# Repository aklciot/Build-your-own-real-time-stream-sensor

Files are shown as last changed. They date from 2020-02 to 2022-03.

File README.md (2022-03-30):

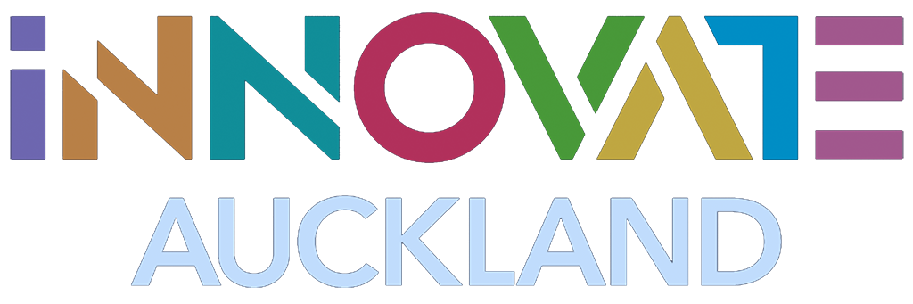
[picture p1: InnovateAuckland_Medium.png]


# Stream Water EC, Temperature and Level Sensor
Build your own automated water quality EC sensor and transmit the data over LoRa radio.
<br>View a live example here: 
https://live.innovateauckland.nz/dashboard/28a59570-c8a9-11ea-a129-5da81effbbe6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

## Selection Criteria for Stream EC Sensor Location:

1.	Fresh water only, non-tidal. The EC 0.1 K sensor is not suited to saltwater.
2.	An active community group willing to periodically check on the sensor, take samples and photographs when events happen and as required
3.	If the sensor will also measure water height, an over water mounting location not exceeding 2.5M above normal water level, this is because the max sonar range is 3.5 Meters
4.	An EC sensor tether location that allows the sensor to move freely in or near the main flow. The sensor cable is around 4 metres in length. This way, water flow automatically maintains a consistent sensor location.
5.	A network gateway location with line of sight 1-2Km of the sensing location.
6.	Ability to easily access the senor unit for maintenance, cleaning and battery changes.
7.	Protecting the sensor in public locations. It is preferrable to locate the sensor for good measurement over avoiding theft or vandalism.  Consider how to disguise or cover the senor in areas that are accessible by the public.

## User Guide
Please read the user guide included here to learn about the sensor installation and operation.
https://github.com/aklciot/StreamECSensor/blob/master/Userguide/USER_GUIDE_WaterEC_Sensor_0.8.8.pdf

## Compiling and loading
This code can be compiled on a standard Arduino GUI.
### Libraries
The following libraries are required:
- OneWire.h (connects data for the dallas sensor)
- DallasTemperature.h (DS18B20 digital thermometer)
- Adafruit_SleepyDog.h  (Power management)
- RH_RF95.h (Radiohead driver for the Hope LoRa radio)
- Ultrasonic.h (driver for the grove ultrasonic sensor)

### PLEASE NOTE:
This sensor is designed to work with the open source LoRa telemetry network and gateway described here:</br>
https://github.com/aklciot/TTGO-Gateway-repeater
</br>

## About this Sensor

### Who should use this guide:

This guide is for anyone interested in creating their own real-time environmental data sensing network.  It explains how to install and use the open source water quality sensor and the data network that makes your sensor data available on the internet.

Some of the concepts in the guide are quite technical, if you’re not sure or need clarification please email us at the address below.

We recommend you have access to people familiar with connecting computer peripherals and WiFi settings.

### What is real-time monitoring?
Low cost Real-time monitoring is an amazing new capability made possible by a collection of technologies commonly referred to as the internet of things (IOT). Most monitoring techniques involve a regular visit to the monitoring location where recordings are made and recorded manually. These visits can be weeks or months apart.  In real time monitoring, measurements are made automatically every few minutes and the information is immediately processed and stored on the internet. This  creates an up to date, long term and detailed record.

### Why is real time monitoring important?

Streams are very sensitive to weather and pollution events. These events can occur over a very short time, often after a few hours or minutes the event is over. Monthly sampling will miss most important events that occur in your stream.
With real time monitoring:

<b>Don’t miss events.</b> Things can change fast in a stream, if you’re not there to see it you’ll miss it, the sensor watches 24/7 and creates a continuous record.</br>
<b>Narrow down the cause.</b> If your stream is monitored at multiple points you can narrow down where and when an event occurred and its possible cause.</br>
<b>Create positive behaviours.</b> We all change how we behave if we know we’re being watched.  With the stream monitor people become aware that dumping and faults are more likely to be detected.</br>
<b>See the effect of restoration work.</b>  The sensor creates long term trend data. The improvements made by restoration work can be shown over time.</br>
<b>You can learn more about your stream and others.</b> Combing your data with the work done by others can lead to new insights previously unavailable.</br>

### How does the stream sensor work?
The sensor is intended to detect acute discharge events into urban waterways that would otherwise go unnoticed. 
It works by monitoring the water electrical conductivity (EC), temperature, and water level. 
Every few minutes the sensor sends data over <a href="https://en.wikipedia.org/wiki/LoRa" target="_blank">LoRa radio</a> to the internet where the time is recorded and the data is processed and stored. 
This sensor is based on low cost open source technology and as such is not a scientific grade water quality meter, however it is good enough to give meaningful information and warnings and let you know when it is time to take a closer look. 
To keep the cost (and maintenance) down, it does not currently monitor other stream health metrics such as dissolved oxygen (DO), pH, Phosphates, bacteria and nutrients.  Some of these will be added in the future though.

### What is EC (Electrical Conductivity in water)?
EC or Electrical Conductivity of water is its ability to conduct an electric current. Salts or other chemicals that dissolve in water can break down into positively and negatively charged ions. These free ions in the water conduct electricity, so the water electrical conductivity depends on the concentration of ions. 
Salinity and total dissolved solids (TDS) are used to calculate the EC of water, which helps to indicate the water’s purity. 
The purer the water the lower the conductivity. To give a real-life example, distilled water is almost an insulator, but saltwater is a very efficient electrical conductor.
<br>
<br>
The system includes the ability to alert on threshold events by SMS text, email or twitter. Data can also be extracted or forwarded to other systems for modeling and trending analysis.
<br>

## Change Log
- Version 2.4 Published to GitHub
- Version 2.3 Added MOSFET power control and grove ultrasonic sensor
- Version 2.2 Added EC K type Calibration to loop
- Version 2.1 Added f_ec = atof(EC); to convert char to float to resolve radio send fault
- Version 2.0 Installed Atlas Scientific EC K=0.1 sensor and EZO circuit.
- Version 1.3 Installed grove ultrasonic to improve power usage.
- Version 1.2 Changed to default LoRa radio spreading factor
- Version 1.1 Corrected water temperature and EC calculation
- Version 1.0 Initial Build

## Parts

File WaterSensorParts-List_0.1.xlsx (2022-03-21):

Parts List BOM: Urban Stream Sensor: Water level, Conductivity and Temperature
 | QTY | Part | Description | Supplier Website | Cost $NZ
 | 1 | Ultrasonic Distance Sensor - 3V or 5V - HC-SR04 compatible - RCWL-1601 | ultrasonic sensor to measure the water height | https://www.tinytronics.nl/shop/en/sensors/distance/ultrasonic-sensor-rcwl-1601
 |  |  |  | https://www.adafruit.com/product/4007 | 10
 | 5 | 4-core Round Screened Audio Cable - Sold per metre. CAT.NO: WB1510 | 5M Sensor Cable | https://www.jaycar.co.nz/4-core-round-screened-audio-cable-sold-per-metre/p/WB1510 | 10
 | 1 | Waterproof DS18B20 Digital temperature sensor + extras | Water temperatue sensor | https://www.adafruit.com/product/381 | 20
 | 1 | Feather 32u4 RFM95 LoRa Radio- 868 or 915 MHz - PRODUCT ID: 3078 | MCU controller CPU that runs the code for taking measurements and sending the data | https://www.adafruit.com/product/3078 | 70
 |  |  |  | https://nz.mouser.com/ProductDetail/Adafruit/3078?qs=AGnqjqvSJvKRStF%2FKXnSuQ%3D%3D
 | 1 | Power control MOSFET | N-Channel Enhancement Mode Field Effect Transistor | https://nz.mouser.com/ProductDetail/onsemi-Fairchild/2N7000?qs=FOlmdCx%252BAA2o%2FKZOTk%2F3hg%3D%3D | 2
 | 1 | Lithium Battery | AA Batteries, pack of four. | https://www.newworld.co.nz/shop/product/5028789_ea_000nw?name=ultimate-lithium-aa-battery | 25
 | 1 | DS18B20 Digital temperature sensor + extras PRODUCT ID: 374 | Air Temperature Sensor | https://www.adafruit.com/product/374 | 10
 | 1 | Atlas Scientific Water EC Conductivity | Conductivity Sensor K0.1 | https://www.atlas-scientific.com/product_pages/kits/ec_k0_1_kit.html | 500
 | 1 | LoRa Data Telemetry Gateway | 2Pcs Wemos® TTGO 868/915MHz SX1276 ESP32 LoRa 0.96 Inch Blue OLED Display bluetooth WIFI Module IOT Development Board | https://www.banggood.com/2Pcs-Wemos-TTGO-868915MHz-SX1276-ESP32-LoRa-0_96-Inch-Blue-OLED-Display-Bluetooth-WIFI-Module-p-1303190.html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 | 100
 | 1 | Sealed Polycarbonate Enclosure 115 x 90 x 55 | Box for housing the sensor | https://www.jaycar.co.nz/sealed-polycarbonate-enclosure-115-x-90-x-55/p/HB6217 | 25
 |  | Total: |  |  | 772

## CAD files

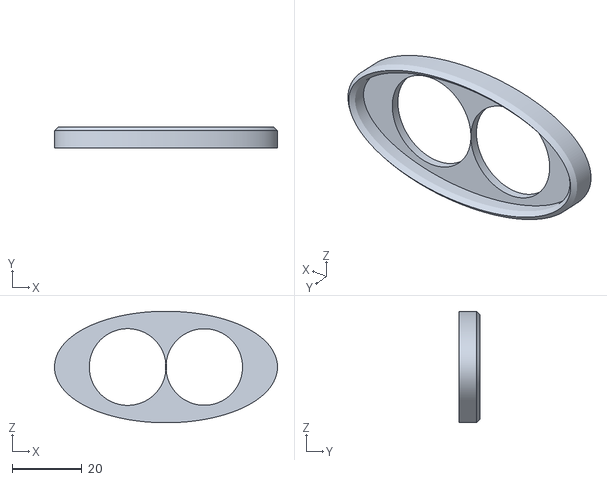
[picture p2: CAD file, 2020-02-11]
3D Files/OuterRing_V1.stl
64.0 x 6.00 x 32.0

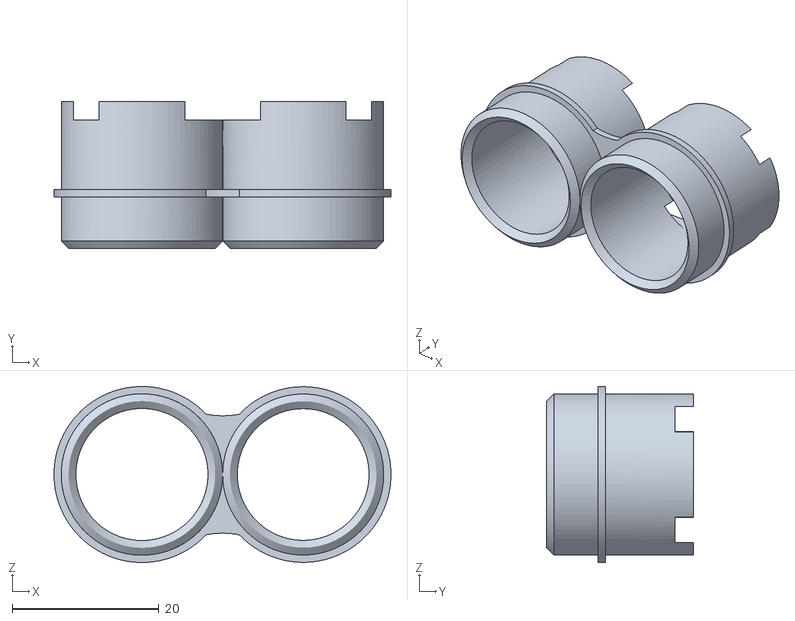
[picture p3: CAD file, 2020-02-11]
3D Files/Rings_V3.stl
45.9 x 20.0 x 24.0

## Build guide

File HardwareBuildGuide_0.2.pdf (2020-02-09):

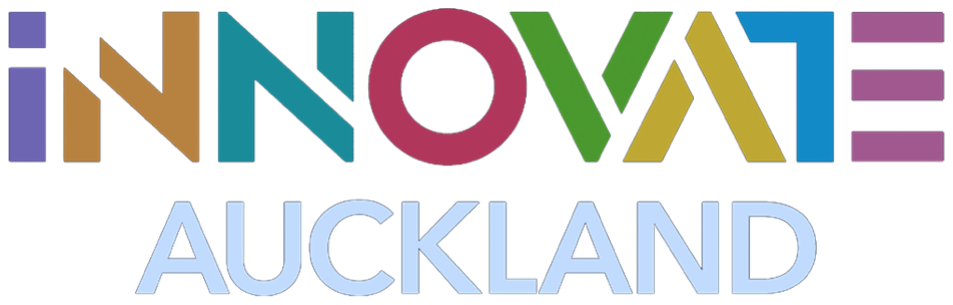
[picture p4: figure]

## Hardware Build Guide:

Water Quality Conductivity Temperature and Level Sensor

Build Guide version 0.2. Warren Davies Draft for Comment

Ultrasonic Sensor Mount with 3D printed insert.

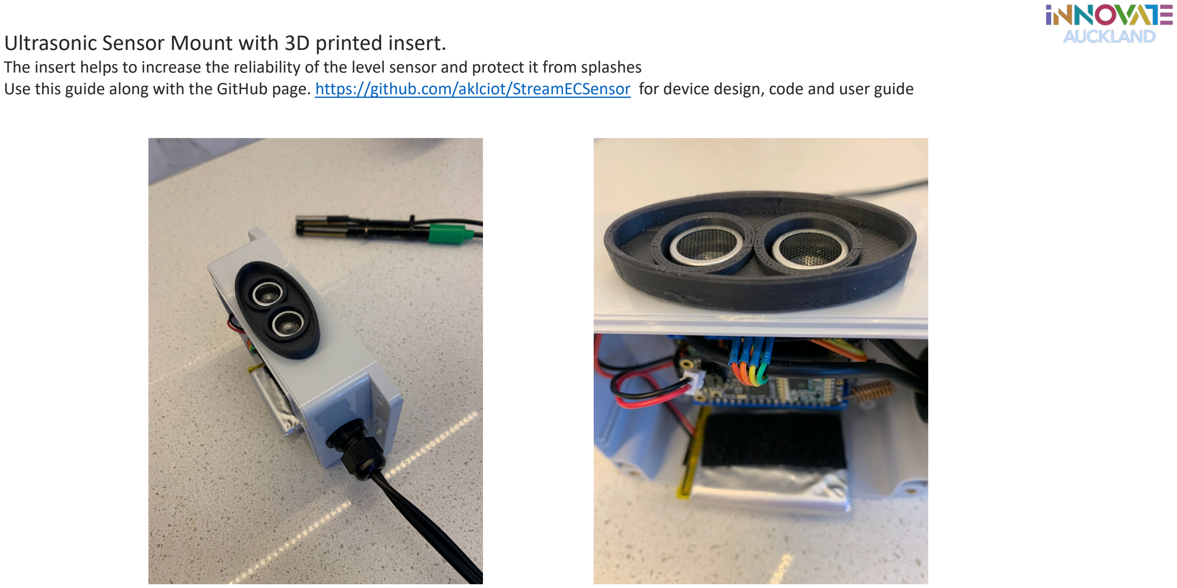
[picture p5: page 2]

The insert helps to increase the reliability of the level sensor and protect it from splashes
Use this guide along with the GitHub page. https://github.com/aklciot/StreamECSensor for device design, code and user guide

Internal Construction.

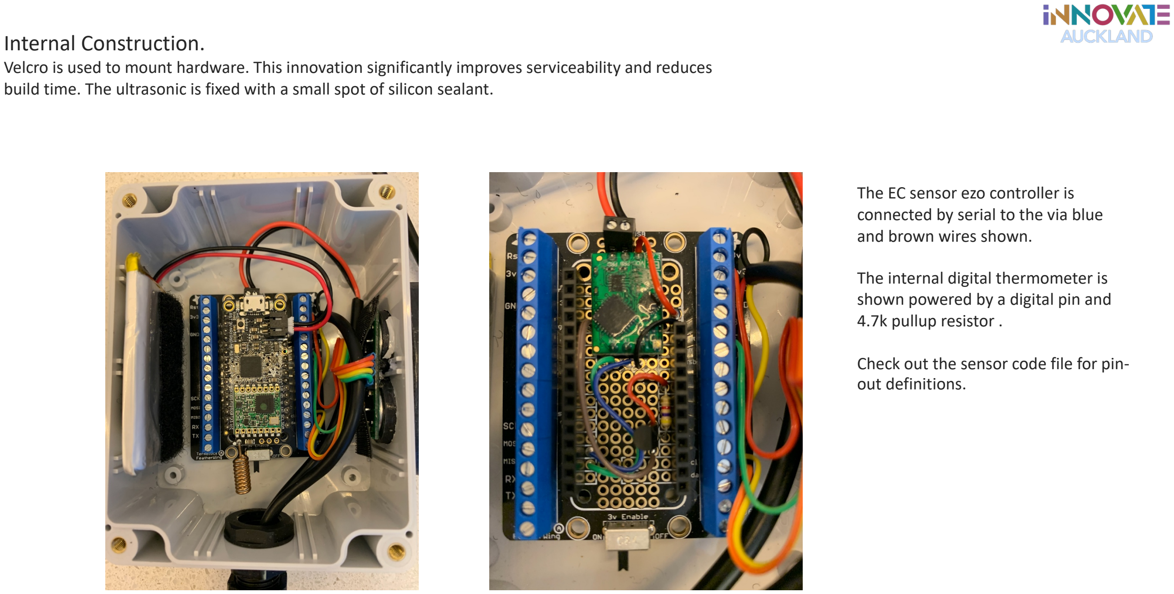
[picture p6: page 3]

Velcro is used to mount hardware. This innovation significantly improves serviceability and reduces build time. The ultrasonic is fixed with a small spot of silicon sealant.

The EC sensor ezo controller is connected by serial to the via blue and brown wires shown.

The internal digital thermometer is shown powered by a digital pin and 4.7k pullup resistor .

Check out the sensor code file for pinout definitions.

Sensor Tether Cable Construction.

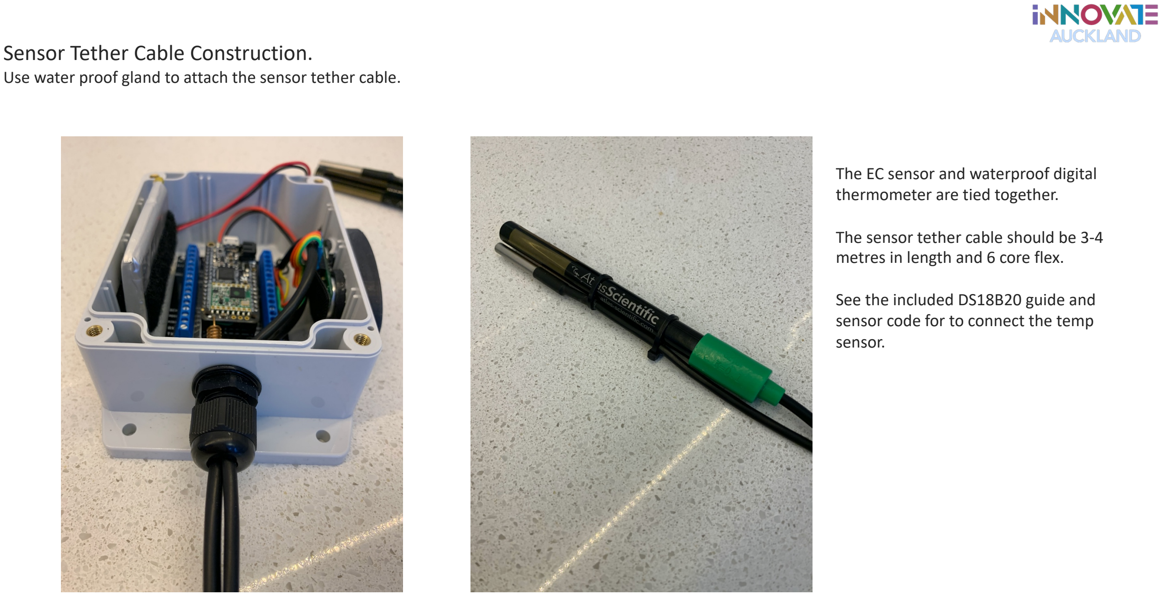
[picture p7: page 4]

Use water proof gland to attach the sensor tether cable.

The EC sensor and waterproof digital thermometer are tied together.

The sensor tether cable should be 3-4 metres in length and 6 core flex.

See the included DS18B20 guide and sensor code for to connect the temp sensor.

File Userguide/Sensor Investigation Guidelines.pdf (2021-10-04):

0

2

0

1

0

3

If you're in the area, observe any changes

in water clarity, level or smell.

Take note of any discolouration from paint,

detergent, oil, foam, sediment or presence

of wastewater, and understand the

potential origins of each.

# TAKE A CLOSER LOOK

Watercare - 09 442 2222 if sewage /

waste water.

Pollution Hotline - 09 377 3107 if

water is discoloured from paint,

detergent, oil, foam, sediment.

# REPORT

0

4

0

5

# Community Stream Sensor

## Investigation guideline

What does the stream normally look like, in

dry weather and after rain? What is the

typical pH level of the stream?

UNDERSTAND THE BASELINE | Review the EC in conjunction with the
| water level and temperature. An increase
| in EC and water level could indicate an
| event caused by heavy rain. An increase
| in EC, water level and temperature could
| indicate a first flush pollution event.

# ANALYSE THE TRENDS

If the stream looks & smells normal, you

can use your Wai Care care to test for pH

and Ammonia. Ammonia is an indicator

of wastewater, and pH an indicator of the

presence of pollutants. If the results are

outside of their thresholds (pH below 5

or over 9, Ammonia above 3) call

Pollution Hotline.

# SAMPLE

*If taking a sample, please remember to only to do so if wearing gloves and can safely access the stream bank. Follow your Wai Care Health & Safety plan

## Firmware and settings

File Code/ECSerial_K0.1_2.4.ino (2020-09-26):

// **********************************************************************************
// INNOVATE AUCKLAND Water Quality EC Sensor Version 2.4
// EZO-ECTM Embedded Conductivity Circuit Conductivity = μS/cm
// Adafruit featherM0 with LoRa RFM95, Dallas 18B20 sensors and sleepydog power management
// Includes 2X Dallas 18B20 digital Air and Water temperature sensors
// WD Version 2.4 Published to GitHub
// WD Version 2.3 Added MOSFET power control and grove ultrasonic sensor and library
// WD Version 2.2 Added EC K type Calibration to loop
// WD Version 2.1 Added f_ec = atof(EC); to convert char to float to resolve radio send fault
// WD Version 2.0 Installed Atlas Scientific EC K=0.1 sensor and EZO circuit.
// WD Version 1.3 Installed grove ultrasonic to improve power usage.
// WD Version 1.2 Changed to default LoRa radio spreading factor
// WD Version 1.1 Corrected water temperature and EC calculation
// WD Version 1.0 Initial Build
// **********************************************************************************

/*
The Non-Profit Open Software License version 3.0 (NPOSL-3.0)

Copyright (c) 2019 Innovate Auckland

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
This software may not be used for commercial purposes.

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

THE SOFTWARE IS PROVIDED "AS IS", WITHOUT WARRANTY OF ANY KIND, EXPRESS OR
IMPLIED, INCLUDING BUT NOT LIMITED TO THE WARRANTIES OF MERCHANTABILITY,
FITNESS FOR A PARTICULAR PURPOSE AND NONINFRINGEMENT. IN NO EVENT SHALL THE
AUTHORS OR COPYRIGHT HOLDERS BE LIABLE FOR ANY CLAIM, DAMAGES OR OTHER
LIABILITY, WHETHER IN AN ACTION OF CONTRACT, TORT OR OTHERWISE, ARISING FROM,
OUT OF OR IN CONNECTION WITH THE SOFTWARE OR THE USE OR OTHER DEALINGS IN THE
SOFTWARE
.*/

#include <OneWire.h>
#include <DallasTemperature.h>
#include <Adafruit_SleepyDog.h>
#include <RH_RF95.h>
#include "Ultrasonic.h"

char* Nodestr = "STRXX";   // Node ID
#define PWRLOOP 19         // Power down, n X 16sec power down


//************************************ Define Connections ***************************
// Settings for feather32u4 LoRa RFM95
/*
  #define RFM95_CS  8
  #define RFM95_RST 4
  #define RFM95_INT 7
  #define VBATPIN   A9 // voltage divider for battery measurement
  #define led       13
*/

// Settings for featherM0 LoRa RFM95
#define RFM95_RST    4
#define RFM95_CS     8
#define RFM95_INT    3
#define VBATPIN      A7 // voltage divider for battery measurement
#define RF95_FREQ 915.0
#define LED          13

#define SensorPWR    12
#define ONE_WIRE_BUS 6 // Dallas data wire is connected to pin 6


String inputstring = "";                              //a string to hold incoming data from the PC
String sensorstring = "";                             //a string to hold the data from the Atlas Scientific product
boolean input_string_complete = false;                //have we received all the data from the PC
boolean sensor_string_complete = false;               //have we received all the data from the Atlas Scientific product

char sensorstring_array[30];                        //we make a char array
char *EC;                                           //char pointer used in string parsing
char *TDS;                                          //char pointer used in string parsing
char *SAL;                                          //char pointer used in string parsing
char *GRAV;                                         //char pointer used in string parsing

// wd variables told hold string values
char Tstr[10];     // Air Temp
char Wstr[10];     // Water temp
char Dstr[10];     // Distance
char ECstr[10];    // EC Level
char Bstr[10];     // Battery Voltage

char buffer[50];
byte sendLen;

float Temp1, WTemp, Bat, f_ec, Dist;
int distance;


//************************************ Load Drivers ********************************

RH_RF95 rf95(RFM95_CS, RFM95_INT);        // wd load driver instance of the radio and name it "rf95"

OneWire oneWire(ONE_WIRE_BUS);            // Setup a oneWire instance to communicate with any OneWire devices

DallasTemperature sensors(&oneWire);      // Pass our oneWire reference to Dallas Temperature.

//Ultrasonic ultrasonic(10, 11);
Ultrasonic ultrasonic(10);  //grove 3 wire


void setup() {

  //while (!Serial);
  Serial.begin(9600);                                 //set baud rate for the hardware serial port_0 to 9600
  delay(100);
  Serial1.begin(9600);                               //set baud rate for the software serial port_1 to 9600

  Serial.println("Serial Started");

  pinMode(LED, OUTPUT);        // initialize digital pin as an output.
  pinMode(SensorPWR, OUTPUT);
  pinMode(RFM95_RST, OUTPUT);
  digitalWrite(RFM95_RST, HIGH);

  // manual reset
  digitalWrite(RFM95_RST, LOW);
  delay(10);
  digitalWrite(RFM95_RST, HIGH);
  delay(10);

  //wd initialise radio
  while (!rf95.init()) {
    Serial.println("LoRa radio init failed");
    while (1);
  }
 
  Serial.println("LoRa radio init OK!");

  // Defaults after init are 434.0MHz, modulation GFSK_Rb250Fd250, +13dbM
  if (!rf95.setFrequency(RF95_FREQ)) {
    Serial.println("setFrequency failed");
    while (1);
  }
  Serial.print("Set Freq to: "); Serial.println(RF95_FREQ);

  // wd set radio tx power and use PA false
  rf95.setTxPower(13, false);
  rf95.printRegisters();  //Print all the RFM95 register values
  /*
      // Start up the Dallas Temperature library
      sensors.begin();
  */

  inputstring.reserve(10);                            // set aside some bytes for receiving data from the PC
  sensorstring.reserve(30);                           // set aside some bytes for receiving data from Atlas Scientific product
  Serial1.print("Factory");                           // Factory rest EZO-EC Atlas Scientific
  Serial1.print('\r');
  delay(1000);
  Serial1.print("K,0.1");                             // Set K level of the EZO-EC Atlas Scientific product
  Serial1.print('\r');

  digitalWrite(LED, LOW);
  delay(50);
  digitalWrite(LED, HIGH);
  delay(50);
  digitalWrite(LED, LOW);
  delay(50);
  digitalWrite(LED, HIGH);
  delay(50);
  digitalWrite(LED, LOW);
  delay(5000);  //wait for recode

}


/**********wd dtostrf function for feather M0 *************************/
#if defined(ARDUINO_SAMD_ZERO) || defined(ARDUINO_SAMD_MKR1000)
static char *dtostrf (double val, signed char width, unsigned char prec, char *sout) {
  char fmt[20];
  sprintf(fmt, "%%%d.%df", width, prec);
  sprintf(sout, fmt, val);
  return sout;
}
#endif


// used for serial input to the EZO-EC circuit
void serialEvent() {                                  //if the hardware serial port_0 receives a char
  inputstring = Serial.readStringUntil(13);           //read the string until we see a <CR>
  input_string_complete = true;                       //set the flag used to tell if we have received a completed string from the PC
}


/***************** Main Loop *************************/
void loop() {
  // Power Up and Start Sensors
  Serial.println();
  Serial.println("Sensor Start");
  // Power Up Sensors
  digitalWrite(SensorPWR, HIGH);
  delay(500);
  sensors.begin();
  delay(1000);
  //Serial1.print("Wake");                            //send wake string to the Atlas Scientific product
  //Serial1.print('\r');
  Serial1.print("K,0.1");                             // Set K level of the EZO-EC Atlas Scientific product
  Serial1.print('\r');
  delay(1000);


  // Measure Temperatures
  Serial.println("Requesting temperatures...");
  sensors.requestTemperatures();
  Serial.println("DONE");
  Temp1 = sensors.getTempCByIndex(1); //index 0, first sensor, air temp
  //Temp1 = 20; //index 0, first sensor, water temp sesnor
  WTemp = sensors.getTempCByIndex(0); //index 1, second sensor, water temp
  //WTemp = 25; //index 1, second sensor, water temp

  // Measure EC level, call read EZO-EC code
  uint8_t ReadEC;
  for (ReadEC = 0; ReadEC < 100; ReadEC++) {
    ECloop();                                //then call ec sensor function
  }


  // Measure water level, read UltraSonic
  distance = ultrasonic.MeasureInCentimeters();
  //distance = 76;


  // Measure battery
  float measuredvbat = analogRead(VBATPIN);
  measuredvbat *= 2; // we divided by 2, so multiply back
  measuredvbat *= 3.3; // Multiply by 3.3V, our reference voltage
  measuredvbat /= 1024; // convert to voltage
  Bat = measuredvbat;


  // convert doubles to char-string, add char-string to buffer array
  dtostrf(Temp1, 1, 1, Tstr);
  dtostrf(WTemp, 1, 1, Wstr);
  dtostrf(distance, 1, 0, Dstr);
  dtostrf(f_ec, 1, 0, ECstr);
  dtostrf(Bat, 1, 1, Bstr);
  //sprintf(buffer, "%s,%s,%s,%s,%s,%s,!", Nodestr, Tstr, Wstr, Dstr, EC, Bstr);
  sprintf(buffer, "%s,%s,%s,%s,%s,%s", Nodestr, Tstr, Wstr, Dstr, ECstr, Bstr);

  // wd send buffer and send length to radio
  sendLen = strlen(buffer);

  rf95.send((uint8_t *) buffer, sendLen);
  rf95.waitPacketSent();
  rf95.sleep();


  // wd serial diagnostics
  Serial.println("  ....................  " );
  Serial.println();
  Serial.print("Temp1: "); Serial.println(Temp1);
  Serial.print("WTemp: "); Serial.println(WTemp);
  Serial.print("Distance: "); Serial.println(distance);
  Serial.print("EC Value: "); Serial.print(EC); Serial.println(" uS/cm2");
  Serial.print("Battery: "); Serial.println(Bat);
  Serial.println();
  Serial.print("Send Data: "); Serial.println(buffer);
  Serial.print("Send Length: "); Serial.println(sendLen);
  Serial.println("  ....................  " );
  Serial.println();
  Serial.println("Going to sleep in one second...");
  delay(1000);

  // To entering low power sleep mode for loop
  Serial.println("Shutdown Loop");
  digitalWrite(SensorPWR, LOW);                         // Power Down Sensors
  Serial1.print("Sleep");                               //send sleep string to the Atlas Scientific product
  Serial1.print('\r');
  uint8_t i;
  for (i = 0; i < PWRLOOP; i++) {
    //Watchdog.sleep();  //enable watchdog only after your sensor and code is tested
    Serial.print(i);    Serial.println(", ");
    digitalWrite(LED, HIGH);
    delay(50);
    digitalWrite(LED, LOW);
    delay(1000); //comment out this delay to reduce power utlisation 
  }
}


void ECloop() {

  if (input_string_complete) {                        //if a string from the PC has been received in its entirety
    Serial1.print(inputstring);                      //send that string to the Atlas Scientific product
    Serial1.print('\r');                             //add a <CR> to the end of the string
    inputstring = "";                                 //clear the string
    input_string_complete = false;                    //reset the flag used to tell if we have received a completed string from the PC
  }

  if (Serial1.available() > 0) {                     //if we see that the Atlas Scientific product has sent a character
    char inchar = (char)Serial1.read();              //get the char we just received
    sensorstring += inchar;                           //add the char to the var called sensorstring
    if (inchar == '\r') {                             //if the incoming character is a <CR>
      sensor_string_complete = true;                  //set the flag
    }
  }

  if (sensor_string_complete == true) {               //if a string from the Atlas Scientific product has been received in its entirety
    if (isdigit(sensorstring[0]) == false) {          //if the first character in the string is a digit
      Serial.println(sensorstring);                   //send that string to the PC's serial monitor
    }
    else                                              //if the first character in the string is NOT a digit
    {

      sensorstring.toCharArray(sensorstring_array, 30);   //convert the string to a char array
      EC = strtok(sensorstring_array, ",");               //let's pars the array at each comma
      TDS = strtok(NULL, ",");                            //let's pars the array at each comma
      SAL = strtok(NULL, ",");                            //let's pars the array at each comma
      GRAV = strtok(NULL, ",");                           //let's pars the array at each comma
      /*
            Serial.print("EC:");                                //we now print each value we parsed separately
            Serial.println(EC);                                 //this is the EC value

            Serial.print("TDS:");                               //we now print each value we parsed separately
            Serial.println(TDS);                                //this is the TDS value

            Serial.print("SAL:");                               //we now print each value we parsed separately
            Serial.println(SAL);                                //this is the salinity value

            Serial.print("GRAV:");                              //we now print each value we parsed separately
            Serial.println(GRAV);                               //this is the specific gravity
            Serial.println();                                   //this just makes the output easier to read
      */
      f_ec = atof(EC);                                    //convert the char to a float
    }
    sensorstring = "";                                //clear the string
    sensor_string_complete = false;                   //reset the flag used to tell if we have received a completed string from the Atlas Scientific product
  }
}

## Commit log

2020-02-08 Using the EC probe
2020-02-08 Parts List
    components
    [WaterSensorParts-List.xlsx]
2020-02-08 Water Sensor Code, EC, Level, Temp and LoRa
    Arduino code
2020-02-08 Stream Sensor and Network User Guide
    how it works
2020-02-09 Water EC Sensor Hardware Guide
2020-02-09 Arduino Sensor Code for Adafruit LoRa M0
2020-02-11 Upload 3D files for box sensor insert
    [OuterRing_V1.stl, Rings_V3.stl]
2020-02-11 Sensor User Guide, the print friendly version.
2020-02-11 User Guide, Sensor and Network Gateway
2020-02-25 User Guide Water Quality Conductivity Sensor
2020-02-25 Water Sensor User Guide
    Details on installation and operation
2020-08-26 Parts List
    [WaterSensorParts-List.xlsx]
2020-09-26 Water Quality EC Sensor Code
2022-03-21 Updated BOM March 2022
    [WaterSensorParts-List_0.1.xlsx]
2023-03-14 IMSC Gen6 Econode Sensor
    This code utilises the Econode Gen6 sensor unit to enable water temperature monitoring. Please refer to the learning guide for details.
